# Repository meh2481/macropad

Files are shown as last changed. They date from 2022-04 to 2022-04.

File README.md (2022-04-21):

# macropad
Just a 6-key macropad but mine is better because RGB amirite

Archived as there are too many problems:
- Need a resister per RGB input, not one per output, as constant current across the RGBLED distorts the color otherwise. That's a lot of SMD components.
- The RPi Pico has a limited number of PWM units, not enough for running all of the RGBLEDs, and they were hooked up incorrectly anyway.
- Idea was ditched in favor of streamdekc instead.

# Materials
Parts used (Can easily be subbed for something similar):
- 1x [Raspberry Pi Pico](https://www.raspberrypi.com/products/raspberry-pi-pico/)
- 1x [I2C OLED Display](https://www.adafruit.com/product/4440)
- 6x [Kailh Choc Switch](http://www.kailh.com/en/Products/Ks/CS/) (Linear or clicky with spring mechanism removed)
- 6x [Clear Kailh CHOC Keycaps](https://www.adafruit.com/product/5110)
- 6x [Diffused Rectangular RGB LEDs (5 x 2.5mm)](https://www.adafruit.com/product/2739) or something that fits in the Kailh holes
- MicroUSB cable
- 4x [M3-ish size plastic screws](https://www.amazon.com/dp/B00GDYDCC0) or similar

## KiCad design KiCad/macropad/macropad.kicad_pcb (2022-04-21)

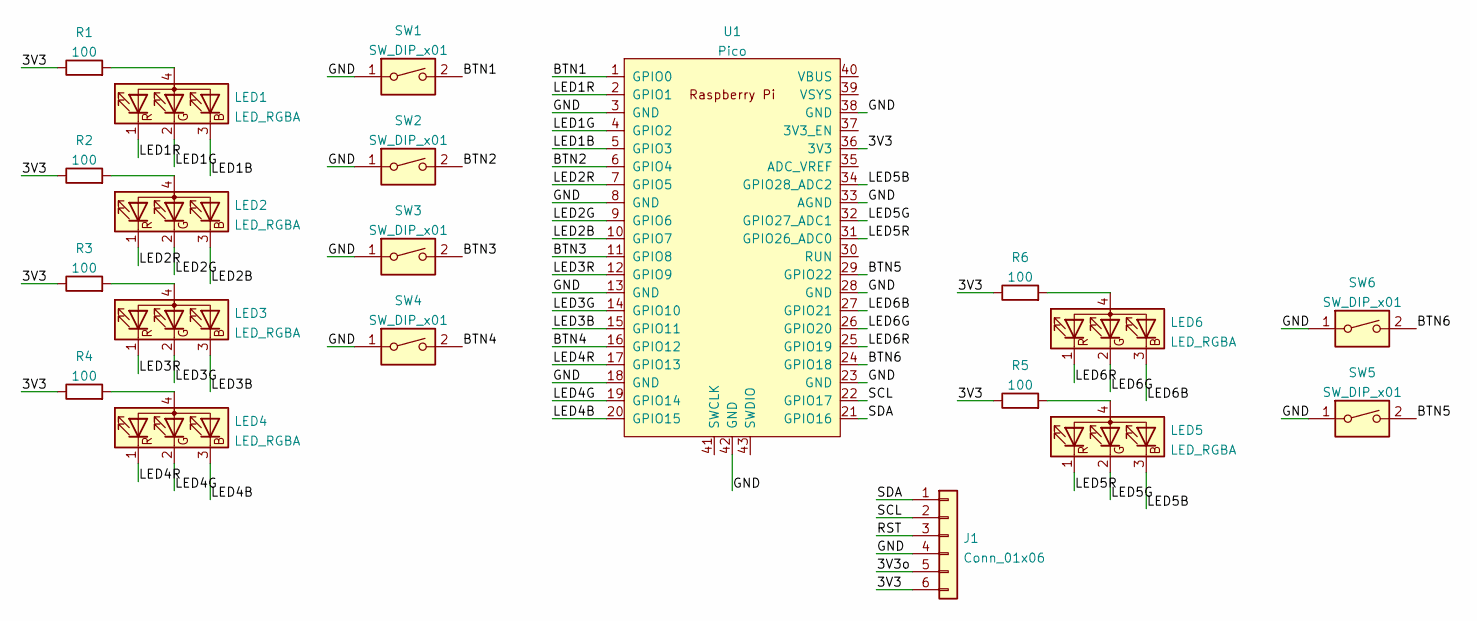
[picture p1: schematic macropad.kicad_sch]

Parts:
J1: Conn_01x06; PinHeader_1x06_P2.54mm_Vertical
LED1, LED2, LED3, LED4, LED5, LED6: LED_RGBA; 1.5mmRGBALED
R1, R2, R3, R4, R5, R6: 100; R_Axial_DIN0309_L9.0mm_D3.2mm_P12.70mm_Horizontal; LCSC C25076
SW1, SW2, SW3, SW4, SW5, SW6: SW_DIP_x01; Kailh_socket_PG1350
U1: Pico; RPi_Pico_SMD

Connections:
/3V3: J1.6, R1.1, R2.1, R3.1, R4.1, R5.1, R6.1, U1.36 (3V3)
/3V3o: J1.5
/BTN1: SW1.2, U1.1 (GPIO0)
/BTN2: SW2.2, U1.6 (GPIO4)
/BTN3: SW3.2, U1.11 (GPIO8)
/BTN4: SW4.2, U1.16 (GPIO12)
/BTN5: SW5.2, U1.29 (GPIO22)
/BTN6: SW6.2, U1.24 (GPIO18)
/GND: J1.4, SW1.1, SW2.1, SW3.1, SW4.1, SW5.1, SW6.1, U1.3 (GND), U1.8 (GND), U1.13 (GND), U1.18 (GND), U1.23 (GND), U1.28 (GND), U1.33 (AGND), U1.38 (GND), U1.42 (GND)
/LED1B: LED1.3 (BK), U1.5 (GPIO3)
/LED1G: LED1.2 (GK), U1.4 (GPIO2)
/LED1R: LED1.1 (RK), U1.2 (GPIO1)
/LED2B: LED2.3 (BK), U1.10 (GPIO7)
/LED2G: LED2.2 (GK), U1.9 (GPIO6)
/LED2R: LED2.1 (RK), U1.7 (GPIO5)
/LED3B: LED3.3 (BK), U1.15 (GPIO11)
/LED3G: LED3.2 (GK), U1.14 (GPIO10)
/LED3R: LED3.1 (RK), U1.12 (GPIO9)
/LED4B: LED4.3 (BK), U1.20 (GPIO15)
/LED4G: LED4.2 (GK), U1.19 (GPIO14)
/LED4R: LED4.1 (RK), U1.17 (GPIO13)
/LED5B: LED5.3 (BK), U1.34 (GPIO28_ADC2)
/LED5G: LED5.2 (GK), U1.32 (GPIO27_ADC1)
/LED5R: LED5.1 (RK), U1.31 (GPIO26_ADC0)
/LED6B: LED6.3 (BK), U1.27 (GPIO21)
/LED6G: LED6.2 (GK), U1.26 (GPIO20)
/LED6R: LED6.1 (RK), U1.25 (GPIO19)
/RST: J1.3
/SCL: J1.2, U1.22 (GPIO17)
/SDA: J1.1, U1.21 (GPIO16)
unnamed: LED1.4 (A), R1.2
unnamed: LED2.4 (A), R2.2
unnamed: LED3.4 (A), R3.2
unnamed: LED4.4 (A), R4.2
unnamed: LED5.4 (A), R5.2
unnamed: LED6.4 (A), R6.2

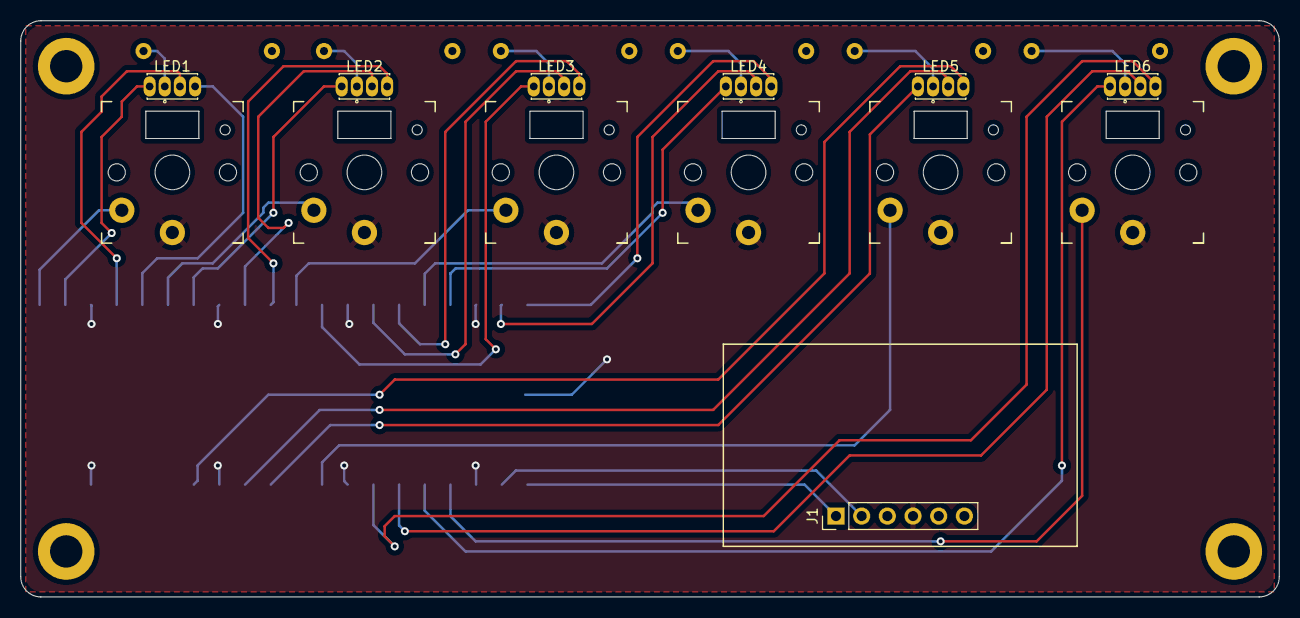
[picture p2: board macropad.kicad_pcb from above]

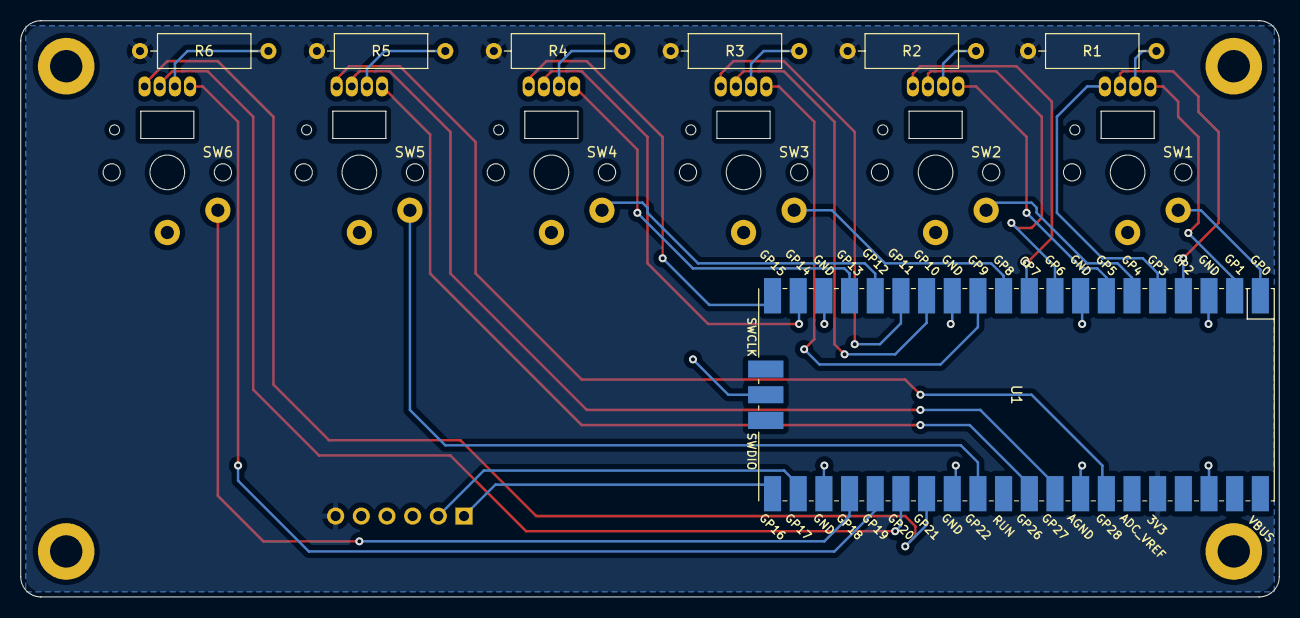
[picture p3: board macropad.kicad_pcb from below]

Board: 2 copper layers, 124.5 x 57.0 mm, 20 parts (7 on the bottom side), 34 nets.

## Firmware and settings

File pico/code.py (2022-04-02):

import time
import board
import pwmio
import usb_hid
from adafruit_hid.keyboard import Keyboard
from adafruit_hid.keycode import Keycode
from digitalio import DigitalInOut, Direction, Pull
from adafruit_debouncer import Debouncer

# Setup PWM for LEDs
leds_r = [
    pwmio.PWMOut(board.GP1, variable_frequency=False, duty_cycle=65535),
    pwmio.PWMOut(board.GP5, variable_frequency=False, duty_cycle=65535),
    pwmio.PWMOut(board.GP9, variable_frequency=False, duty_cycle=65535),
    pwmio.PWMOut(board.GP13, variable_frequency=False, duty_cycle=65535),
    pwmio.PWMOut(board.GP19, variable_frequency=False, duty_cycle=65535),
    pwmio.PWMOut(board.GP26, variable_frequency=False, duty_cycle=65535)
]

leds_g = [
    pwmio.PWMOut(board.GP2, variable_frequency=False, duty_cycle=65535),
    pwmio.PWMOut(board.GP6, variable_frequency=False, duty_cycle=65535),
    None, #pwmio.PWMOut(board.GP10, variable_frequency=False, duty_cycle=65535),
    pwmio.PWMOut(board.GP14, variable_frequency=False, duty_cycle=65535),
    pwmio.PWMOut(board.GP20, variable_frequency=False, duty_cycle=65535),
    pwmio.PWMOut(board.GP27, variable_frequency=False, duty_cycle=65535)
]

leds_b = [
    None, #pwmio.PWMOut(board.GP3, variable_frequency=False, duty_cycle=65535),
    pwmio.PWMOut(board.GP7, variable_frequency=False, duty_cycle=65535),
    None, #pwmio.PWMOut(board.GP11, variable_frequency=False, duty_cycle=65535),
    pwmio.PWMOut(board.GP15, variable_frequency=False, duty_cycle=65535),
    None, #pwmio.PWMOut(board.GP21, variable_frequency=False, duty_cycle=65535),
    pwmio.PWMOut(board.GP28, variable_frequency=False, duty_cycle=65535)
]

buttons = [
    DigitalInOut(board.GP0),
    DigitalInOut(board.GP4),
    DigitalInOut(board.GP8),
    DigitalInOut(board.GP12),
    DigitalInOut(board.GP18),
    DigitalInOut(board.GP22)
]

for button in buttons: 
    button.direction = Direction.INPUT
    button.pull = Pull.UP

debounced_buttons = [Debouncer(button) for button in buttons]

kbd = Keyboard(usb_hid.devices)

button_rose_times = [0.0] * len(buttons)

keycodes = [
    Keycode.F13,
    Keycode.F14,
    Keycode.F15,
    Keycode.F16,
    Keycode.F17,
    Keycode.F18
]

def update_led(led, debounced_button, button_rose_time):
    """Update the LED brightness based on the button state."""
    if not led:
        return
    if not debounced_button.value:
        led.duty_cycle = 0
    else:
        time_diff = time.monotonic() - button_rose_time
        if time_diff > 0.75:
            return # Skip updating PWM to prevent flicker
        led.duty_cycle = min(int(65535 * (time_diff / 0.5)), 65535)    # fade out after half a second

while True:
    # Update the debounced button states
    for debounced_button in debounced_buttons:
        debounced_button.update()
    
    # Update LEDs
    for i in range(len(buttons)):
        # For now just fade out blue
        update_led(leds_r[i], debounced_buttons[i], button_rose_times[i])

        # Check for button presses
        if debounced_buttons[i].fell:
            kbd.press(keycodes[i])
        # Check for button releases
        if debounced_buttons[i].rose:
            button_rose_times[i] = time.monotonic()
            kbd.release(keycodes[i])

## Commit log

2022-03-31 Migrate folders, start kicad project
    [macropad.kicad_pcb, macropad.kicad_sch]
2022-04-01 Initial wiring
    [macropad.kicad_pcb, macropad.kicad_sch]
2022-04-01 Settings for gerber export
    [macropad.kicad_pcb, macropad.kicad_sch]
2022-04-01 Add BOM to README
2022-04-02 add PWMs, fix led flicker
    [code.py]
2022-04-21 Use THT resistors, correct Kailh key layout, giving up on this project for now in favor of streamdekc
    [macropad.kicad_pcb, macropad.kicad_sch]
